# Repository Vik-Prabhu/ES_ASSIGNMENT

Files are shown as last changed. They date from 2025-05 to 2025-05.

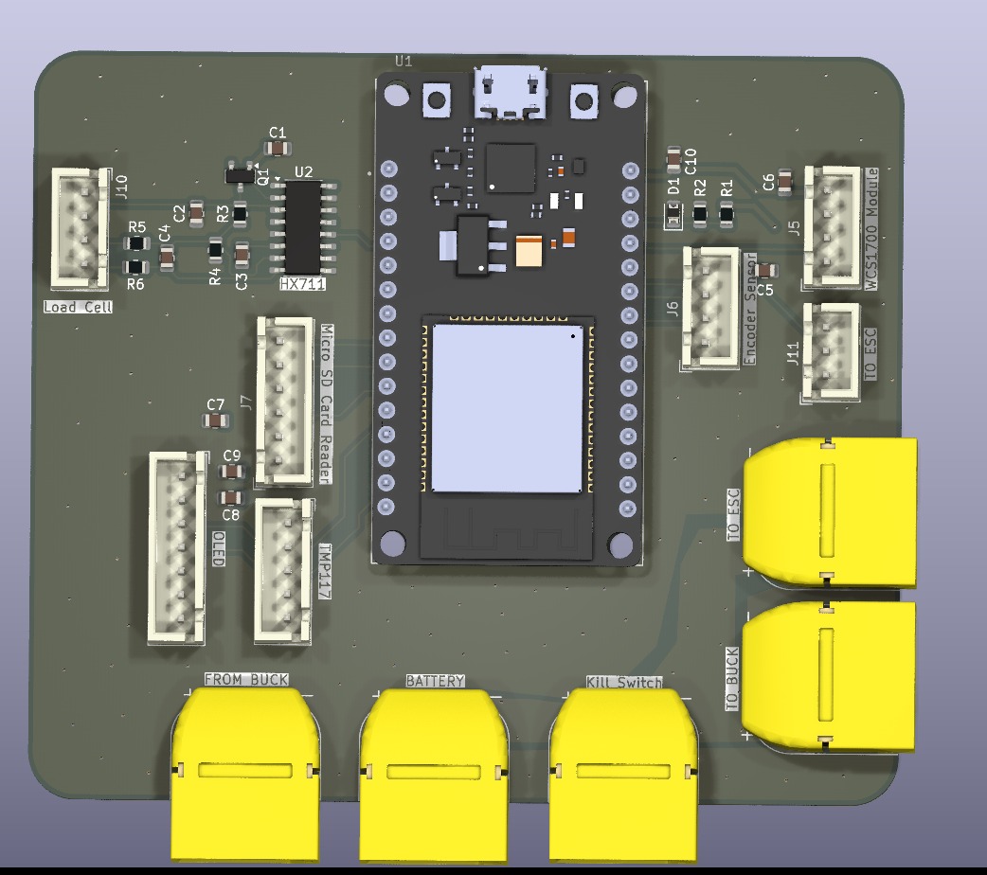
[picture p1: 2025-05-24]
3D_VIEW2.jpg

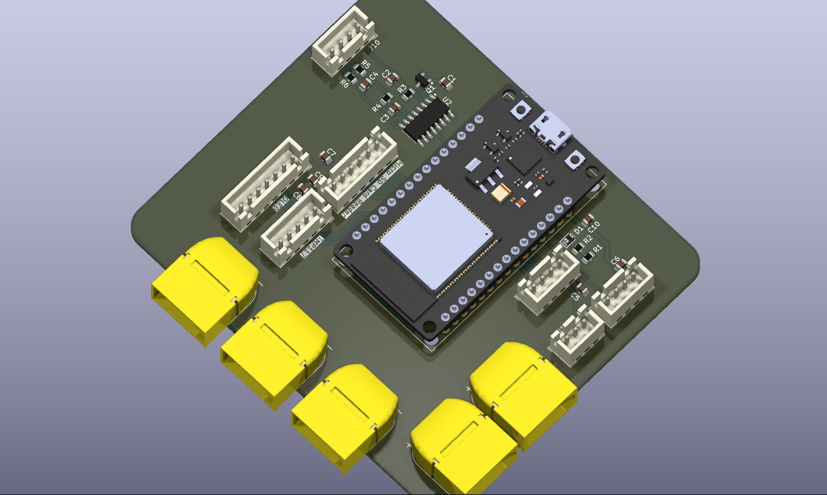
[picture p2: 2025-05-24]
3D_VIEW.jpg

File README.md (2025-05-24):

## Buy Links to the modules used
- [HX711 IC](https://evelta.com/24bit-5v-analog-to-digital-converter-adc/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)
- [TMP117](https://robu.in/product/smartelex-high-precision-temperature-sensor-tmp117/)
- [2.42in OLED](https://robu.in/product/waveshare-2-42inch-oled-display-module-128x64-resolution-spi-i2c-communication/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)
- [Optical Encoder](https://robu.in/product/orange-1000-ppr-ab-phase-incremental-optical-rotary-encoder/)
- [MicroSD Card Reader Module](https://robu.in/product/micro-sd-card-module/#tab-specification)
- [WCS1700 Module](https://robu.in/product/wcs1700-hall-current-sensor-with-over-current-protection/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)

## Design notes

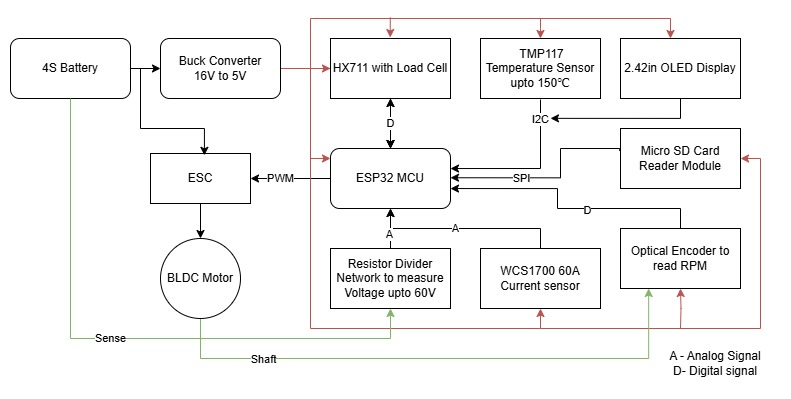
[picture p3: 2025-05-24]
Block_Diagram.jpg

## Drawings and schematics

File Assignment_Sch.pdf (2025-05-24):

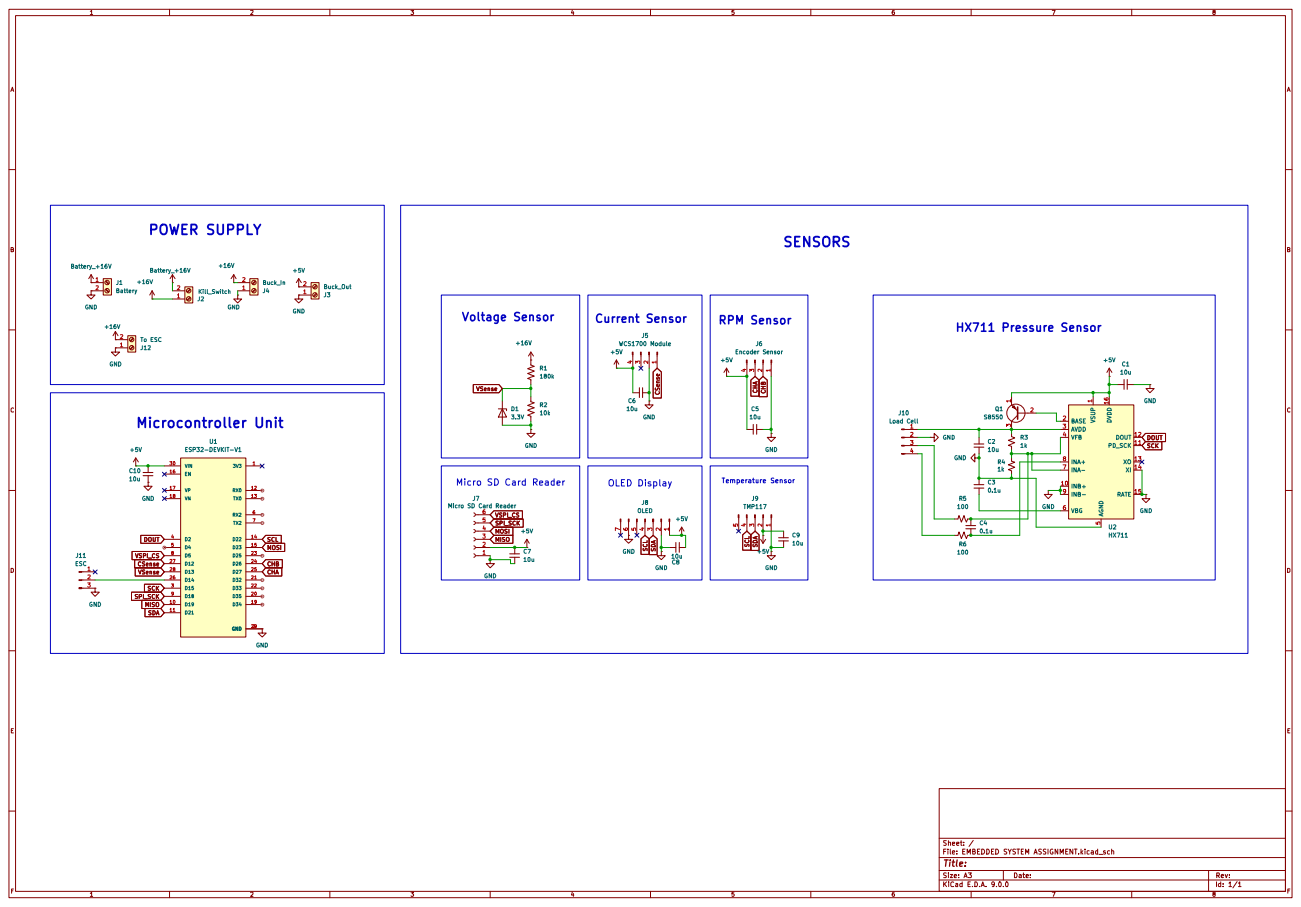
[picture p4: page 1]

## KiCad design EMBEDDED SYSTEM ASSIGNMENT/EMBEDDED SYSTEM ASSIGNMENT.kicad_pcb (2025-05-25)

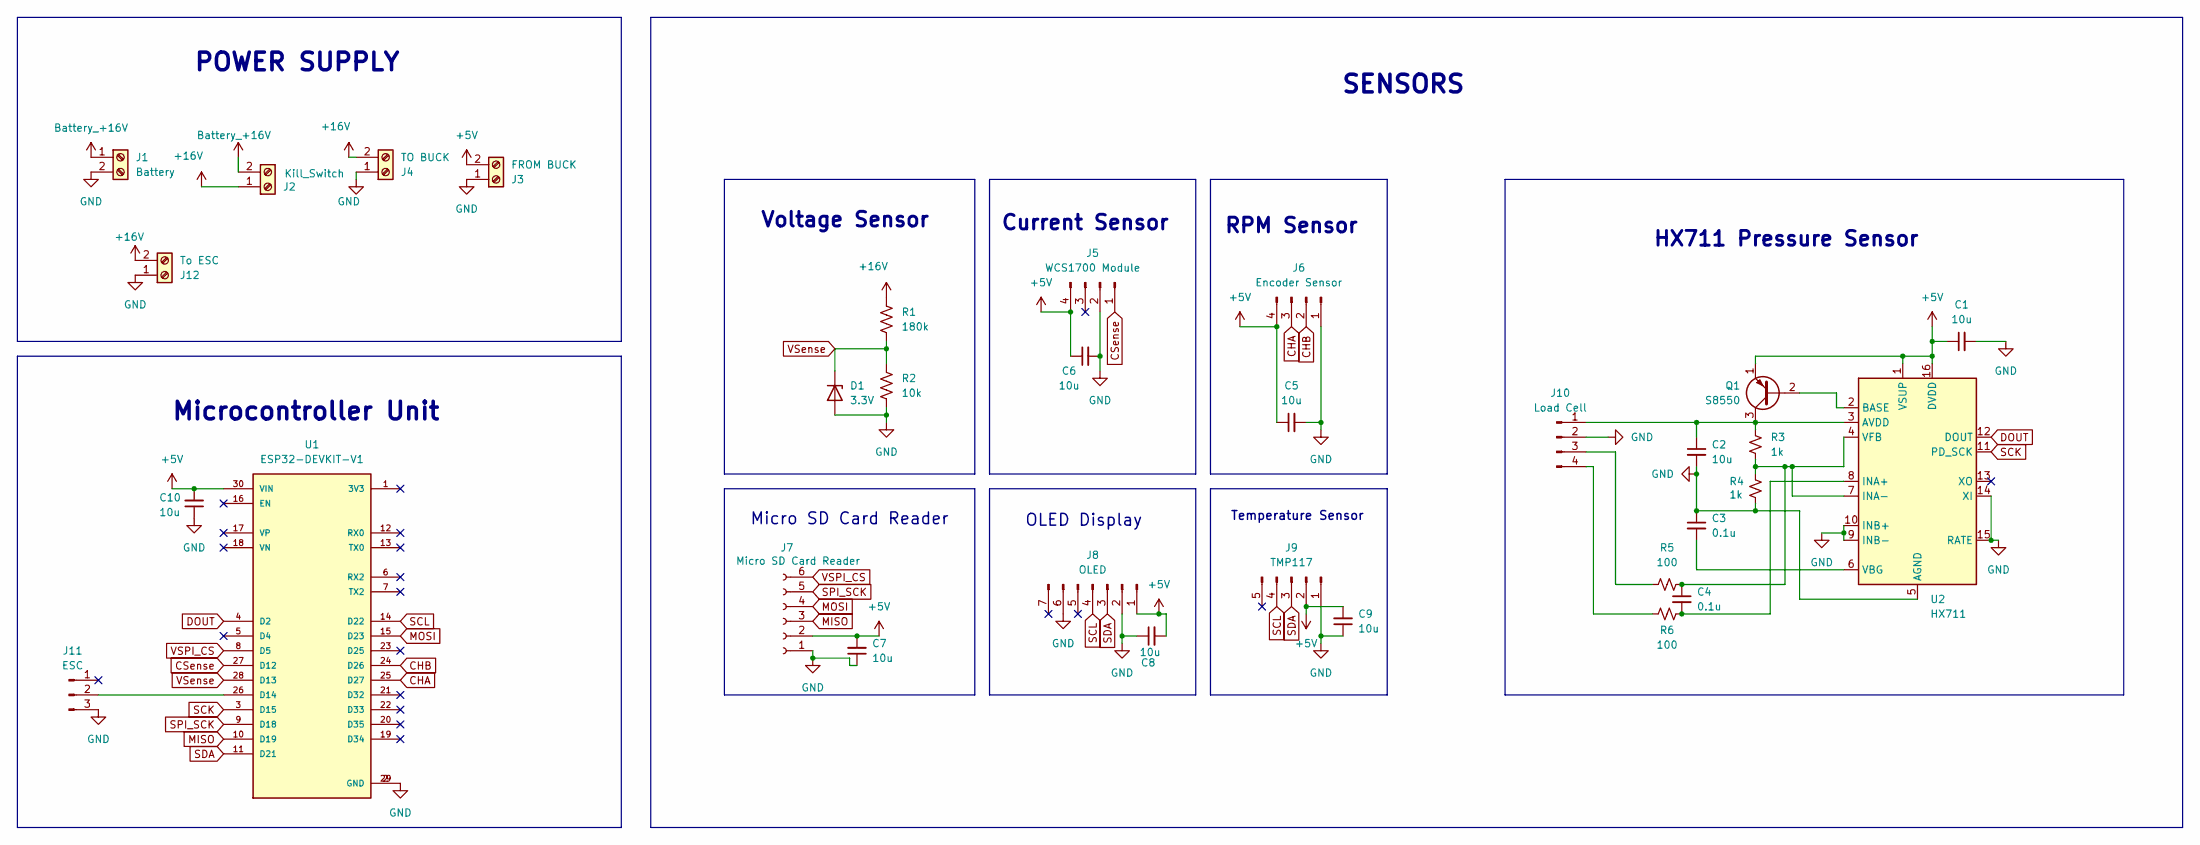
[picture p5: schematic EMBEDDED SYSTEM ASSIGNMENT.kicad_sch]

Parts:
C1, C2, C5, C6, C7, C8, C9, C10: 10u; C_0805_2012Metric
C3, C4: 0.1u; C_0805_2012Metric
D1: 3.3V; D_0805_2012Metric
J1: Battery; AMASS_XT60PW-M_1x02_P7.20mm_Horizontal
J2: Kill_Switch; AMASS_XT60PW-M_1x02_P7.20mm_Horizontal
J3: FROM BUCK; AMASS_XT60PW-M_1x02_P7.20mm_Horizontal
J4: TO BUCK; AMASS_XT60PW-M_1x02_P7.20mm_Horizontal
J5: WCS1700 Module; JST_XH_B4B-XH-A_1x04_P2.50mm_Vertical
J6: Encoder Sensor; JST_XH_B4B-XH-A_1x04_P2.50mm_Vertical
J7: Micro SD Card Reader; JST_XH_B6B-XH-A_1x06_P2.50mm_Vertical
J8: OLED; JST_XH_B7B-XH-A_1x07_P2.50mm_Vertical
J9: TMP117; JST_XH_B5B-XH-A_1x05_P2.50mm_Vertical
J10: Load Cell; JST_XH_B4B-XH-A_1x04_P2.50mm_Vertical
J11: ESC; JST_XH_B3B-XH-A_1x03_P2.50mm_Vertical
J12: To ESC; AMASS_XT60PW-M_1x02_P7.20mm_Horizontal
Q1: S8550; SOT-23
R1: 180k; R_0805_2012Metric
R2: 10k; R_0805_2012Metric
R3, R4: 1k; R_0805_2012Metric
R5, R6: 100; R_0805_2012Metric
U1: ESP32-DEVKIT-V1; MODULE_ESP32_DEVKIT_V1; PARTREV N/A
U2: HX711; SOP-16_3.9x9.9mm_P1.27mm

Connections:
+5V: C1.1, C5.1, C6.1, C7.2, C8.2, C9.2, C10.2, J3.2, J5.4, J6.4, J7.2, J8.1, J9.2, Q1.1 (E), U1.30 (VIN), U2.1 (VSUP), U2.16 (DVDD)
+16V: J2.1, J4.2, J12.2, R1.1
Battery_+16V: J1.1, J2.2
CHA: J6.3, U1.25 (D27)
CHB: J6.2, U1.24 (D26)
CSense: J5.1, U1.27 (D12)
DOUT: U1.4 (D2), U2.12 (DOUT)
GND: C1.2, C2.2, C3.1, C5.2, C6.2, C7.1, C8.1, C9.1, C10.1, D1.2 (A), J1.2, J3.1, J4.1, J5.2, J6.1, J7.1, J8.2, J8.6, J9.1, J10.2, J11.3, J12.1, R2.2, R4.2, U1.2 (GND), U1.29 (GND), U2.5 (AGND), U2.9 (INB-), U2.10 (INB+), U2.14 (XI), U2.15 (RATE)
MISO: J7.3, U1.10 (D19)
MOSI: J7.4, U1.15 (D23)
unnamed: C2.1, J10.1, Q1.3 (C), R3.1, U2.3 (AVDD)
unnamed: J10.3, R5.1
unnamed: J10.4, R6.1
unnamed: J11.2, U1.26 (D14)
unnamed: Q1.2 (B), U2.2 (BASE)
unnamed: C4.2, R6.2, U2.8 (INA+)
unnamed: C4.1, R3.2, R4.1, R5.2, U2.4 (VFB), U2.7 (INA-)
unnamed: C3.2, U2.6 (VBG)
SCK: U1.3 (D15), U2.11 (PD_SCK)
SCL: J8.4, J9.4, U1.14 (D22)
SDA: J8.3, J9.3, U1.11 (D21)
SPI_SCK: J7.5, U1.9 (D18)
VSPI_CS: J7.6, U1.8 (D5)
VSense: D1.1 (K), R1.2, R2.1, U1.28 (D13)

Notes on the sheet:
Temperature Sensor
Microcontroller Unit
SENSORS
OLED Display
HX711 Pressure Sensor
Micro SD Card Reader
RPM Sensor
POWER SUPPLY
Current Sensor
Voltage Sensor

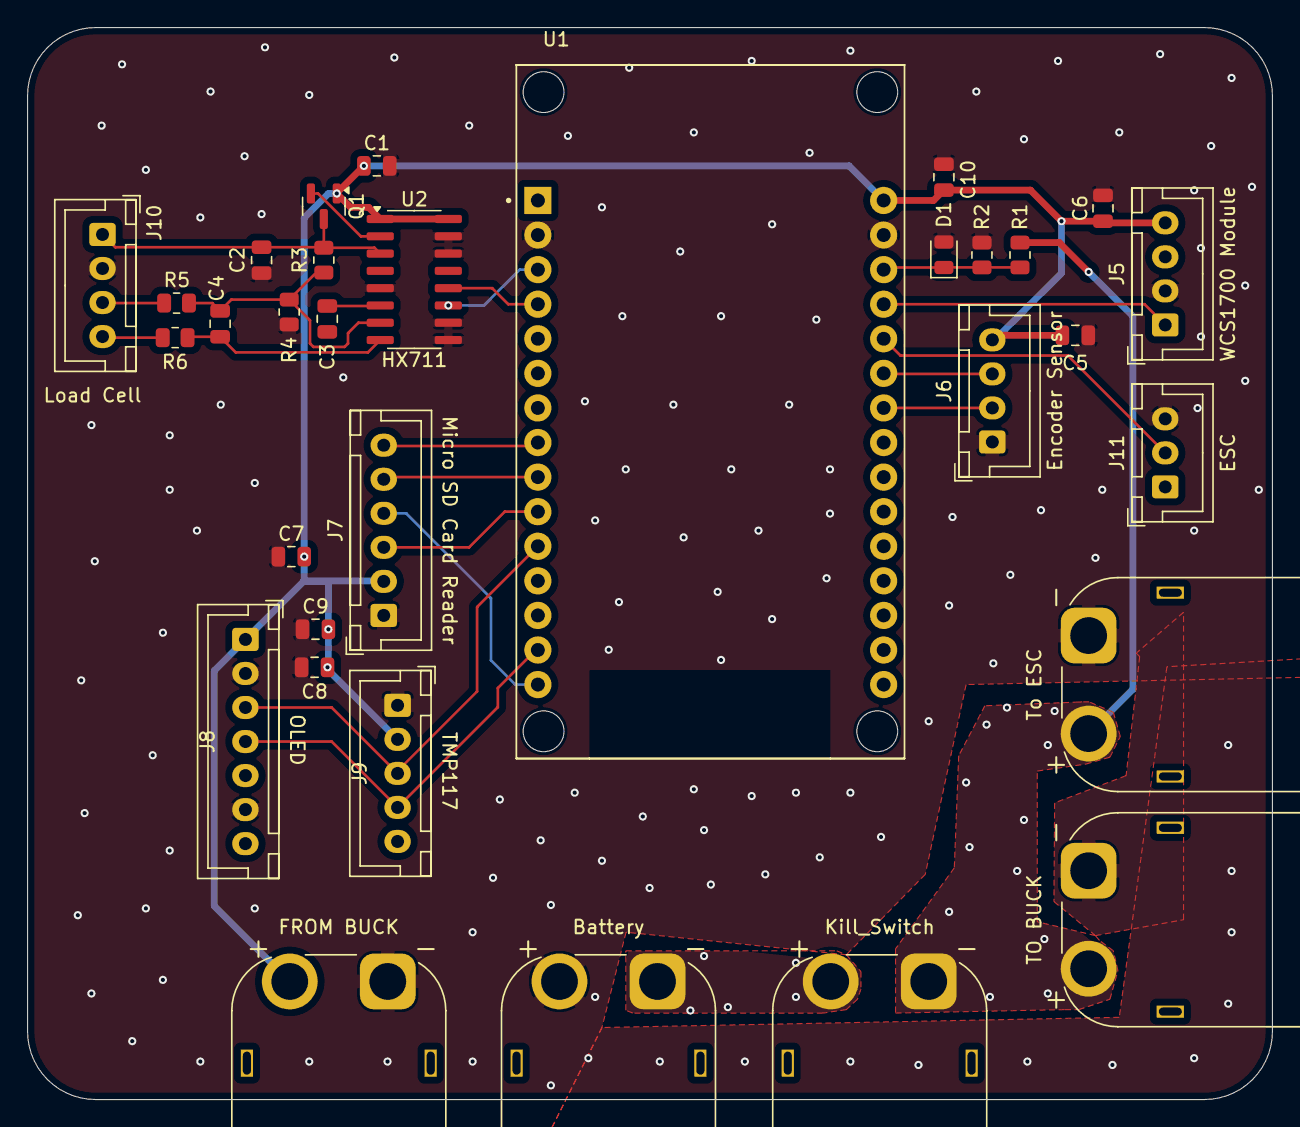
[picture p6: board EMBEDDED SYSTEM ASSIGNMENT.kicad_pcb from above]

Board: 2 copper layers, 91.4 x 78.7 mm, 32 parts (0 on the bottom side), 24 nets.

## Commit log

2025-05-24 inital commit
    [EMBEDDED SYSTEM ASSIGNMENT.kicad_pcb, EMBEDDED SYSTEM ASSIGNMENT.kicad_sch]
2025-05-24 Final touches
    [EMBEDDED SYSTEM ASSIGNMENT.kicad_pcb]
2025-05-25 errors resolved
    [EMBEDDED SYSTEM ASSIGNMENT.kicad_pcb, EMBEDDED SYSTEM ASSIGNMENT.kicad_sch]
